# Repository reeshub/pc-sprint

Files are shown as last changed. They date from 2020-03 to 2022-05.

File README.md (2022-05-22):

# PC-SPRINT

## Navigating This Document

This README has become somewhat unwieldy, so here's an index.

- [Introduction to PC-SPRINT](#introduction-to-pc-sprint) - A quick introduction to the device and how it works.
  - [YouTube Video](#youtube-video) - A YouTube video for those who aren't keen on reading
- [Original File Listing](#original-file-listing) - The original design and accompanying files as released by Doug Severson in 1985.
- [Retro Canada KiCAD Files](#retro-canada-kicad-files) - KiCAD and gerber files drawn up by [VCFed Forum](http://www.vcfed.org/forum/forum.php) user "Retro Canada" for PCB fabrication.
- [My Own "Retro Canada" Board](#my-own-retro-canada-board) - I had a PCB fabricated and assembled it using the above files.
  - [My Testing](#my-testing) - Notes from my own tests with this board.
  - [My Benchmarks](#my-benchmarks) - Benchmarking results.
    - [Landmark](#landmark) - Results from the Landmark benchmarking tool. 
	- [TOPBENCH](#topbench) - Results from the TOPBENCH benchmarking tool.
	- [CheckIt](#checkit) - Results from the CheckIt diagnostic / benchmarking tool.
	- [MIPS](#mips) - You guessed it. Results from the MIPS benchmarking tool.
	- [Benchmarking Conclusions](#benchmarking-conclusions) - Conclusions on benchmark results.
- [Everything Else](#everything-else) - Other interesting documentation and bits and bobs.
- [License](#license) - Licensing information for this project and documentation.

## Introduction to PC-SPRINT

The PC-SPRINT is a DIY PC accelerator board design released by Doug Severson in 1985 and given away for free in computer magazines and on BBSes of the time. It is designed to allow overclocking of an [Intel 8088](Datasheets/Intel%208088%20Datasheet.pdf)-based computer such as the IBM 5150 / 5155 / 5160 PCs, PCjr, Tandy 1000, Compaq Portable<sup>*</sup>, and I'm sure a whole lot more.

It is highly recommended that the CPU be upgraded to an [NEC V20](https://en.wikipedia.org/wiki/NEC_V20) or equivalent, as the standard 8088 shipped with these early machines will probably not run at clock speeds over the original 4.77MHz. Also the 8087 co-processor, if fitted, will need to be a higher clocked version.

<sup>*</sup> The PC-SPRINT has now been tested with a Compaq Portable 1 and works great! There are a few things to bear in mind which are referenced in [issue #1](/../../issues/1). Many thanks to @cognitivegears for the excellent feedback.

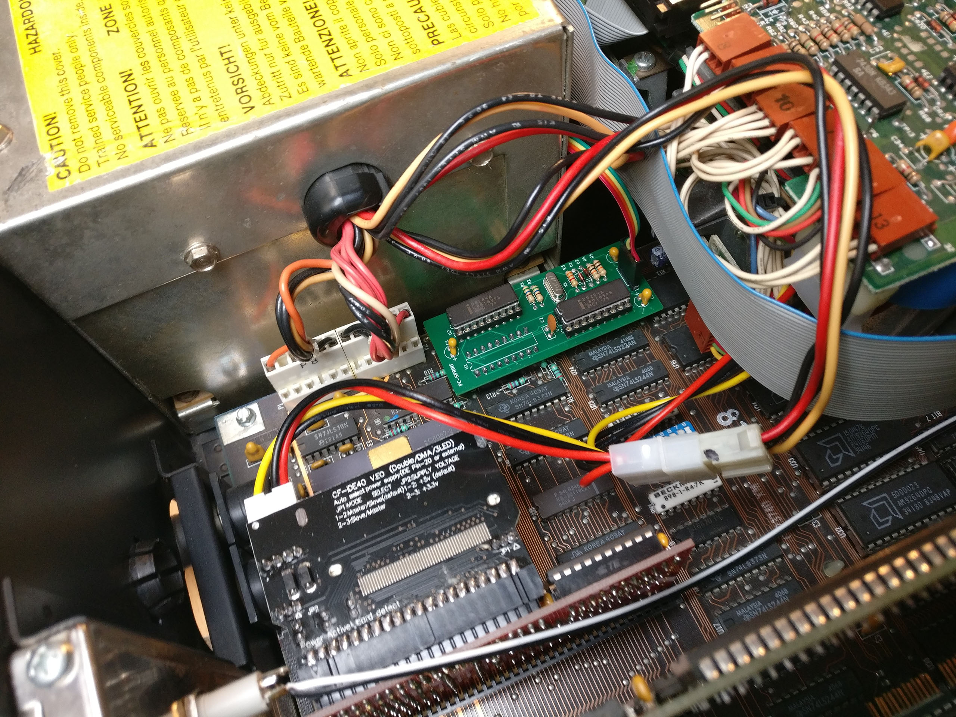
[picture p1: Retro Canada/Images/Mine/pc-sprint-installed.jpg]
My PC-SPRINT Installed In My IBM 5150


In these machines and other contemporary "PC Compatibles" the system clock is usually generated by a 14.318MHz crystal connected to an [Intel 8284A](Datasheets/Intel%208284A-1%20Datasheet.pdf) Clock Generator Driver. The 8284A divides the crystal's signal by 3 giving us our 4.77MHz clock. Unfortunately we can't just replace the crystal on the motherboard as this would play havoc with all sorts of things. The basis of this accelerator is to provide an additional, faster crystal coupled with an additional 8284A to generate a faster clock signal that will be used exclusively by the CPU.

The PC-SPRINT also adds a "Turbo" switch as found on later PCs to enable / disable the higher clock rate and a hardware reset button, which is lacking on the IBM 5150. The included [WARMBOOT.COM](WARMBOOT.COM) utility sets a BIOS flag which skips the RAM test on a warm boot, making the reset very fast even at stock speed.

When the PC-SPRINT is built with the designer's recommended 22.11MHz crystal the CPU will run at a clock speed of 7.37MHz giving an impressive 64% processing speed increase (on paper). Faster speeds may be possible with faster crystals but were not recommended for stability reasons. Note that in order to utilise this accelerator the original 4.77MHz 8088 CPU must be replaced with either a faster version of the same CPU (e.g. 8088-2) or equivalent clone (e.g. [NEC V20](https://en.wikipedia.org/wiki/NEC_V20), which is highly recommended as it brings other benefits).

Much more information is available in the [original documentation](PCSPRINT.DOC) ([PDF](PCSPRINT.DOC.PDF)).

### YouTube Video

I have now also put together a short introductory video. Unfortunately it can't be embedded here, so please click the image below to be taken to YouTube:

PC-SPRINT 8088 Overclocking Tool / Accelerator YouTube Video (https://youtu.be/8oWyogPZ7Bw)

## Original File Listing

Here is a rough index of the files included with the package as originally distributed:

- [1STREAD.ME](1STREAD.ME) - Listing of project files (you're reading a modern adaptation of this)
- [ARTWRK1X.BOT](ARTWRK1X.BOT) - Bottom layer printed circuit artwork 1x size (obsolete printer format) ([PDF](ARTWRK1X.BOT.PDF))
- [ARTWRK1X.TOP](ARTWRK1X.TOP) - Top layer printed circuit artwork 1x size (obsolete printer format) ([PDF](ARTWRK1X.TOP.PDF))
- [ARTWRK2X.BOT](ARTWRK2X.BOT) - Bottom layer printed circuit artwork 2x size (obsolete printer format) ([PDF](ARTWRK2X.BOT.PDF))
- [ARTWRK2X.TOP](ARTWRK2X.TOP) - Top layer printed circuit artwork 2x size (obsolete printer format) ([PDF](ARTWRK2X.TOP.PDF))
- [FEEDTHRU](FEEDTHRU) - Top - bottom "feed through" connection diagram ([PDF](FEEDTHRU.PDF))
- [NOPRTYCK.COM](NOPRTYCHK.COM) - Program to disable parity checks
- [PARTLIST](PARTLIST) - Parts list & placement drawing ([PDF](PARTLIST.PDF))
- [PCSPRINT.BAT](PCSPRINT.BAT) - Batch file to print PC-SPRINT info & drawings 
- **[PCSPRINT.DOC](PCSPRINT.DOC) - Description & construction info ([PDF](PCSPRINT.DOC.PDF))**
- [SCHEMATC](SCHEMATC) - Electronic circuit diagram ([PDF](SCHEMATC.PDF))
- [WARMBOOT.COM](WARMBOOT.COM) - Program to set "warm boot" flag

Note that some files have PDF conversions which were included with the version of the package as received by myself, so I have also linked those above.

The author was keen to include the original unmodified package of files with future revisions, so it is available in [pcsprint_1985.zip](References/pcsprint_1985.zip).

## Retro Canada KiCAD Files

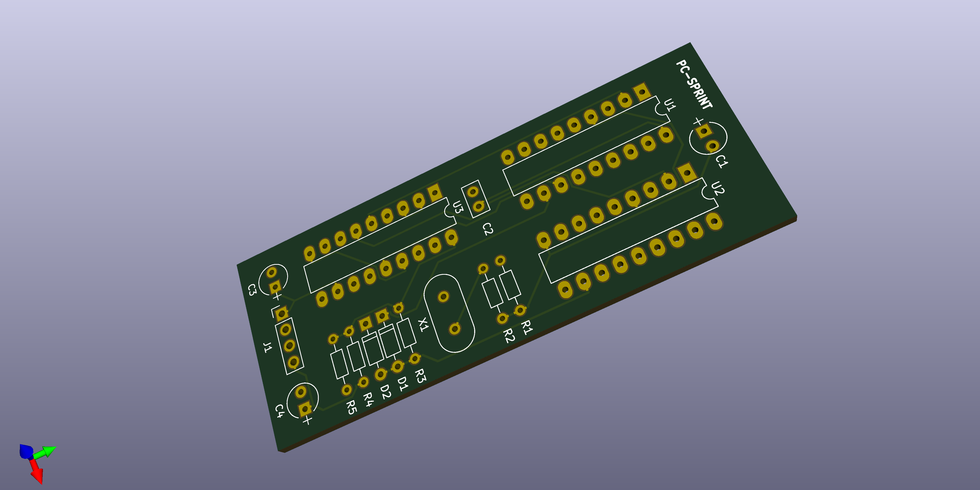
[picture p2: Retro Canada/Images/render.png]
3D Render of Retro Canada's PC-SPRINT


A Vintage Computer Federation forum user by the name of Retro Canada [redrew the original PCB design in KiCAD](http://www.vcfed.org/forum/showthread.php?60803-I-overclocked-my-IBM-5150) and [released the files freely](https://sites.google.com/site/tandycocoloco/dropbox/PC-SPRINT.zip) on November 26th 2017.

I have added a mirror of this KiCAD project [here](Retro%20Canada/PC-SPRINT.zip). The package includes gerber files so KiCAD is not required if you are planning on sending the files directly to a PCB fabricator.

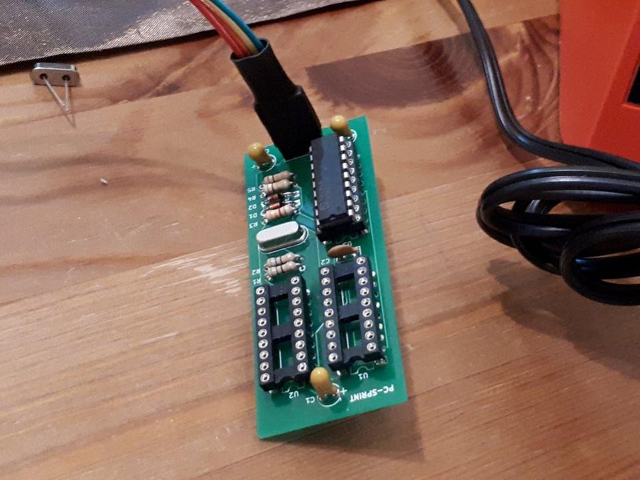
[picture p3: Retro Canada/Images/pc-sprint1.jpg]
Retro Canada's PC-SPRINT


The user built their own based on these files (pictured above - [more of their pictures here](Retro%20Canada/Images)) but could only get it to run reliably up to a 17.43MHz crystal (CPU clock speed 5.81MHz). It is believed that this is related to DMA activity and/or RAM speed, however without the rest of their system specs it's hard to be sure.

### My Own "Retro Canada" Board

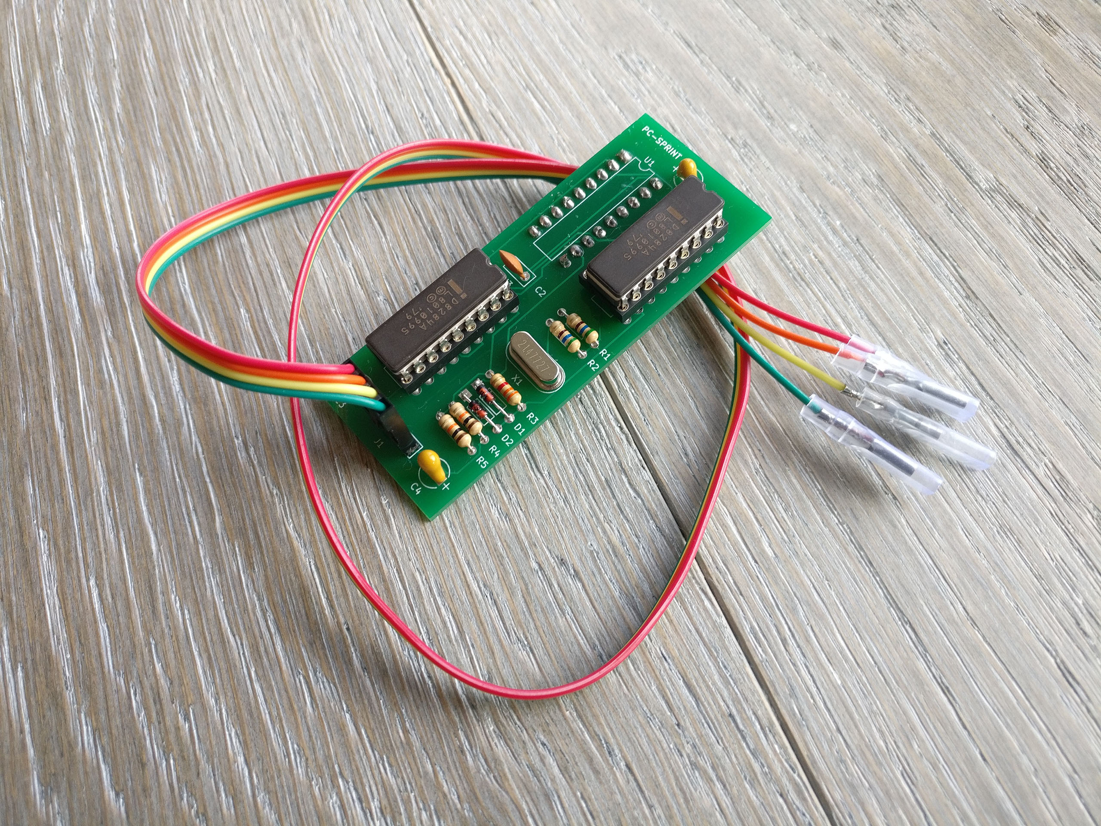
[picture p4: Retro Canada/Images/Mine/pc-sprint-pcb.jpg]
My PC-SPRINT Built Using Retro Canada's Gerber Files


I also successfully built and tested a PC-SPRINT using Retro Canada's files. I used [PCBWay](https://www.pcbway.com/) for my PCB fabrication. Mine has a 21.47727MHz HC-49S crystal giving a CPU clock speed of 7.16MHz - the same as the popular [Tandy 1000 EX and HX](https://en.wikipedia.org/wiki/Tandy_1000#Tandy_1000_EX_and_HX) machines. Thankfully after extensive testing I haven't run into any of the issues experienced by Retro Canada, even at this higher speed.

I have experimented with 22.11MHz and even 24MHz crystals and encountered stability issues at these speeds, so I recommend starting at 21.47MHz.

#### My Testing

Here are the specs of my IBM 5150 as tested:

|Part|Model|Notes|
|---|---|---|
|CPU|[NEC V20](https://en.wikipedia.org/wiki/NEC_V20)|4.77MHz stock / 7.16MHz "turbo" with PC-SPRINT|
|FPU|[Intel 8087-2](https://en.wikipedia.org/wiki/Intel_8087)|8087 co-processor rated up to 8MHz|
|RAM|640KB|(256KB onboard, 384KB on SixPakPlus card)<sup>*</sup>|
|Motherboard|64-256KB [Later Revision](http://www.minuszerodegrees.net/5150/motherboard/5150_motherboard_revisions.htm)|[10/27/82 BIOS](http://minuszerodegrees.net/5150/bios/5150_bios_revisions.htm)|
|HDD|XT-IDE with 512MB CompactFlash card|Running [IDE_XTP.BIN BIOS](https://www.lo-tech.co.uk/wiki/XTIDE_Universal_BIOS)|
|Graphics|IBM CGA<sup>**</sup>||
|Network|3com EtherLink II||
|Floppy|2x Tandon 360KB 5.25"|Stock IBM Floppy ISA interface|
|PSU|Standard 110VAC / 63.5W|
|Operating System|[IBM PC DOS 2000](https://winworldpc.com/product/pc-dos/2000)||

<sup>\* All RAM chips were recently replaced with "New Old Stock" [Samsung KM4164B-15](http://www.minuszerodegrees.net/memory/4164.htm) parts, which have a 150ns access time.</sup>
<sup>\** I have since upgraded to an IBM EGA card (with RAM expansion) and can confirm that the PC-SPRINT works great with this setup. Benchmarks below use the CGA card.</sup>

I have done extensive testing with the above system and had no problems whatsoever. I was expecting issues with DMA activity as others have reported, however have seen none at all. Perhaps this is due to the XT-IDE and its [unusual handling of DMA](https://www.lo-tech.co.uk/xt-cfv3-dma-transfer-mode/). The PC even boots up fine with the turbo mode engaged. Incidentally, cold boot time is 1:02 stock vs. 43 seconds in turbo mode.

The included NOPRTYCHK and WARMBOOT utilities work exactly as advertised with no issues as does the new reset button.

The picture below shows how I installed the turbo and reset buttons in the case. Both are 12mm panel mount push buttons - the turbo button is a latching version:

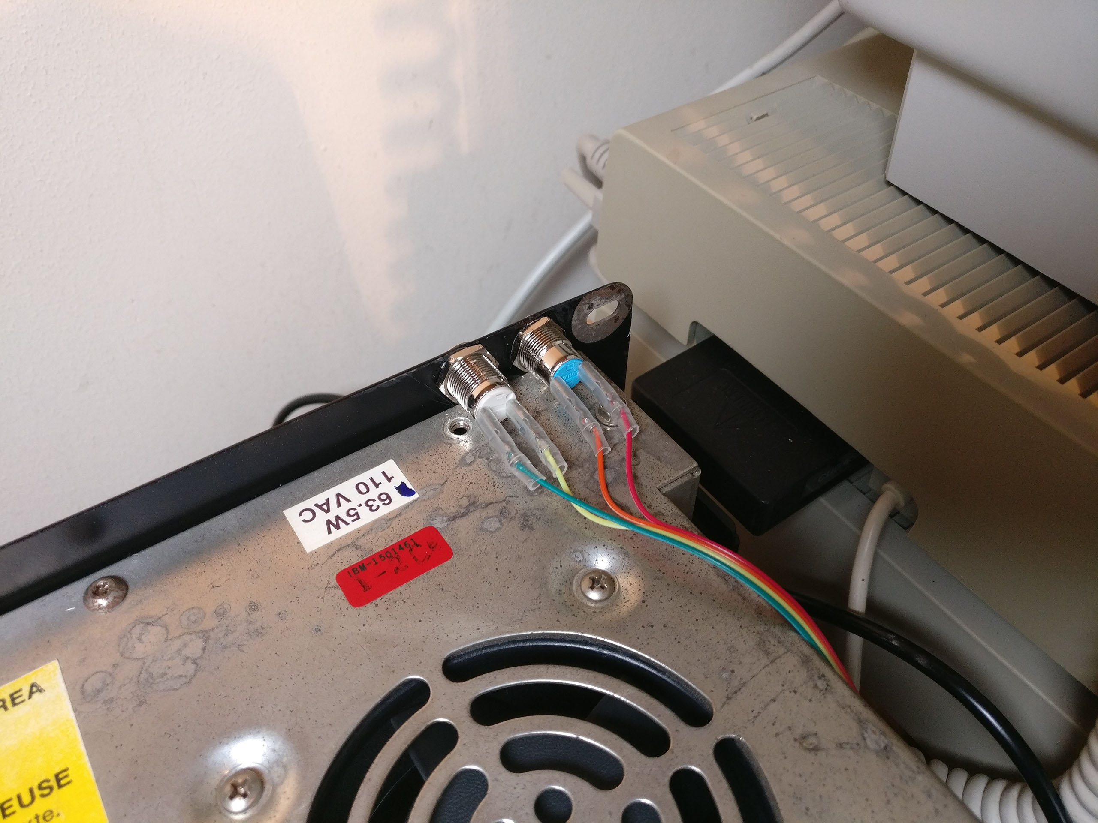
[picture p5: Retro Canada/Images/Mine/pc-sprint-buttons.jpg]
My PC-SPRINT Reset and Turbo Buttons


### My Benchmarks

I ran through a series of benchmarking applications in both turbo and non-turbo mode.

These screenshots (and the videos on [my YouTube channel](https://www.youtube.com/ctrlaltrees)) were captured with a rather elaborate capture setup involving a [CGA2RGB](https://gglabs.us/node/2063), [OSSC](https://videogameperfection.com/products/open-source-scan-converter/) and a [StarTech USB3HDCAP](https://www.startech.com/uk/AV/Converters/Video/usb-3-0-video-capture-device-hdmi-dvi-vga~USB3HDCAP), but that's a tale for another time.

These benchmarks compare the performance of the NEC V20 CPU in stock 4.77MHz and turbo 7.16MHz modes using the PC-SPRINT. Unfortunately I don't have the original Intel 8088 CPU anymore to be able to test, however for some indication of how this system performs compared to a stock 5150 take a look at the [MIPS](#mips) benchmark below.

With the exception of CheckIt, all of these benchmarking tools were downloaded from the [TOPBENCH Other Benchmarks](https://dosbenchmark.wordpress.com/otherbenchmarks/) page.

#### Landmark

Landmark System Speed Test was released in 1984 by Landmark Research Internation Corporation and was one of the first DOS benchmarking tools. Here I'm using version 6.00, the final release from 1993.

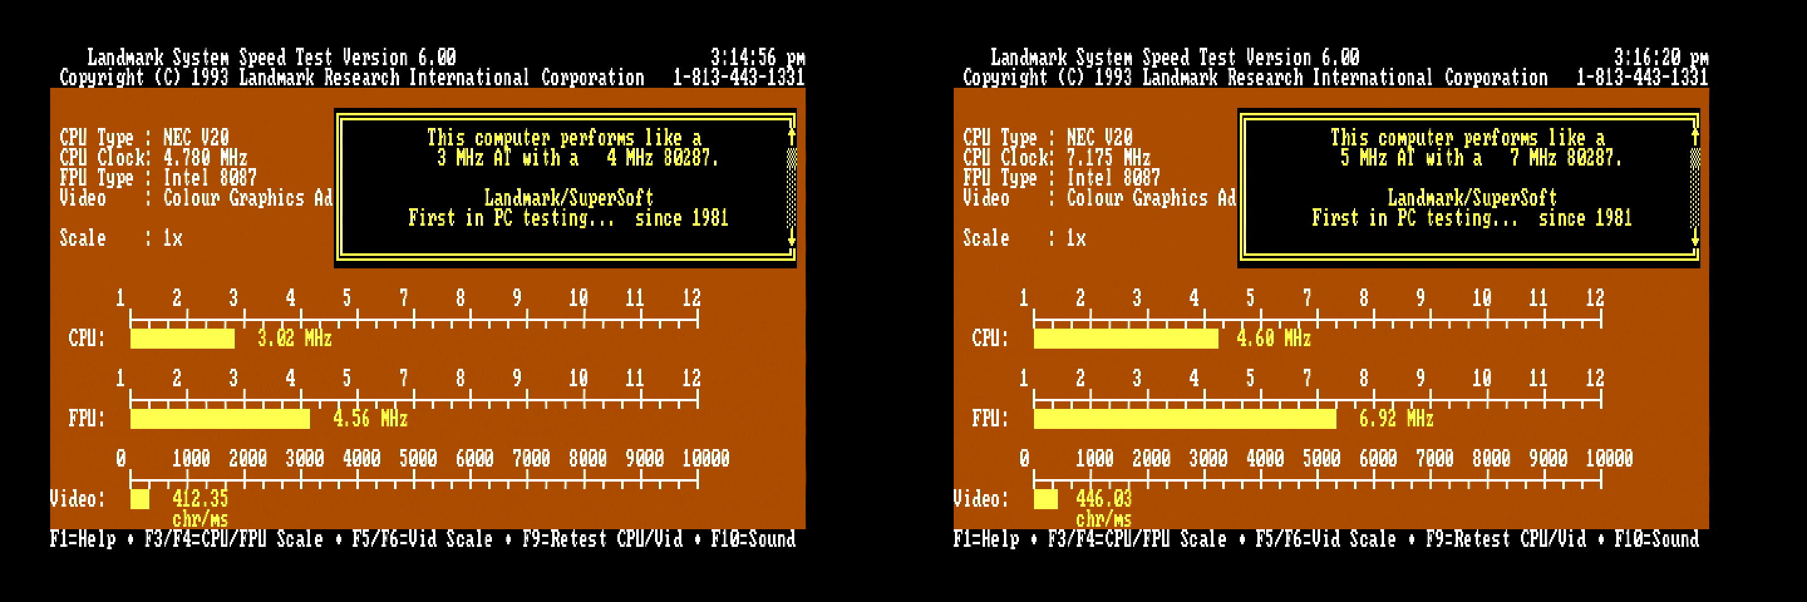
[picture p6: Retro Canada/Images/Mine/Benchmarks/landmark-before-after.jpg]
Landmark Benchmark Before And After Results


|Benchmark|V20 Stock|V20 Turbo|Improvement|
|---|---|---|---|
|CPU<sup>*</sup>|3.02MHz|4.60MHz|52.32%|
|FPU|4.56MHz|6.92MHZ|51.75%|
|Video|412.35 chr/ms|446.03 chr/ms|8.17%|

<sup>\* The way this figure is calculated is interesting (and generally considered wrong) but the percentage increase is all that matters to us. There is more information on the way Landmark arrives at their CPU figure [here](https://dosbenchmark.wordpress.com/research/landmark/).

#### TOPBENCH

[TOPBENCH](https://dosbenchmark.wordpress.com/) is a modern realtime DOS benchmarking tool. An interesting feature is its "database", which allows you to compare your system's performance to that submitted by other users. I'm using version 0.38 with the full database.

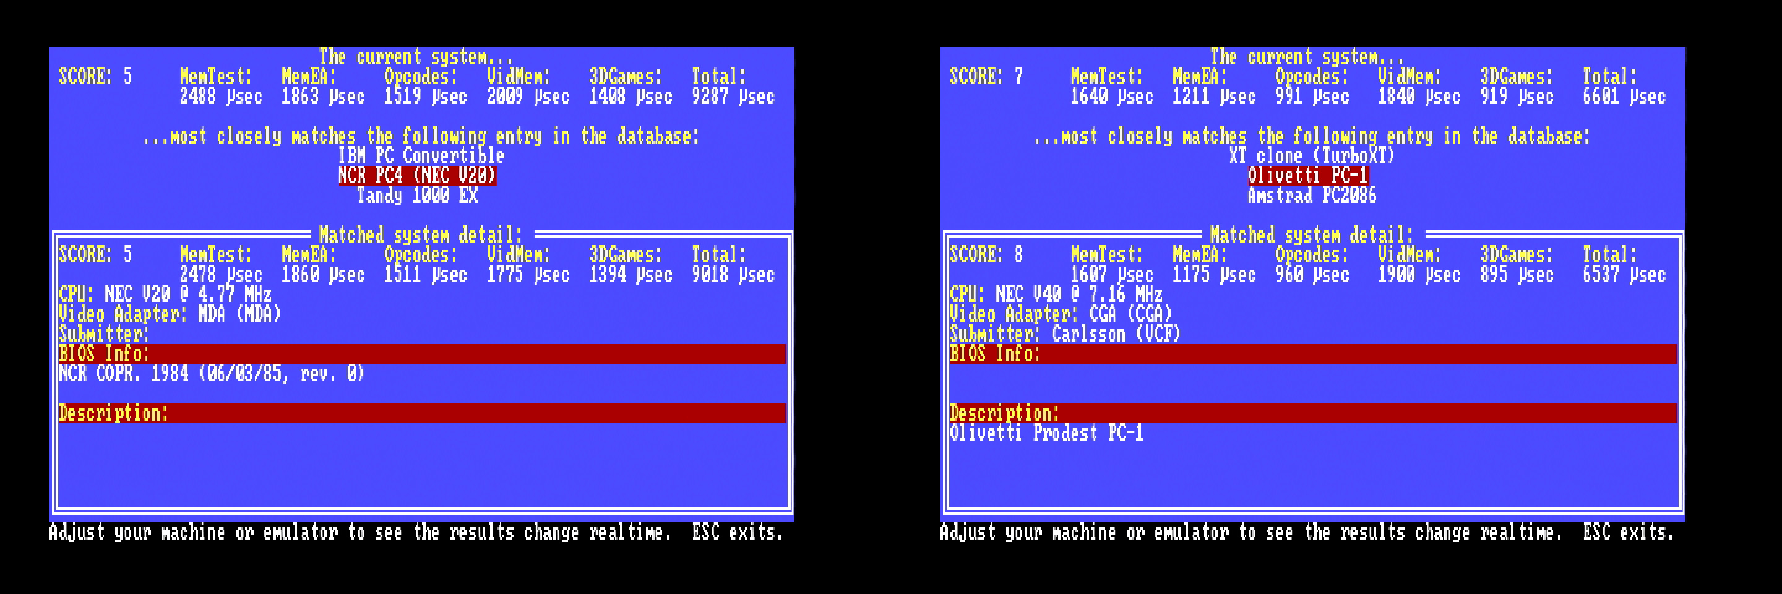
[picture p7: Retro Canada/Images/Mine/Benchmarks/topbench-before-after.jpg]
TOPBENCH Benchmark Before And After Results


Note that TOPBENCH reports the run times of its tests in microseconds, so a lower score is better (faster).

|Benchmark|V20 Stock|V20 Turbo|Improvement|
|---|---|---|---|
|TOPBENCH Score|5|7|2|
|MemTest|2488μ|1640μ|51.71%|
|MemEA|1863μ|1211μ|53.84%|
|Opcodes|1519μ|991μ|53.28%|
|VidMem|2009μ|1840μ|9.18%|
|3DGames|1408μ|919μ|53.21%|
|Total|9287μ|6601μ|40.69%|

According to the database we've gone from an NCR PC4 to an Olivetti PC-1. As I'm not familiar with either of these machines I guess I'll just have to take their word for it. ;)

#### CheckIt

From [WinWorldPC](https://winworldpc.com/product/checkit/30), who said it better than I ever could:

CheckIt, from TouchStone Software Corporation, is a diagnostic tool for generic PC/XT/AT compatible computers. It can perform tests on RAM, hard disks, video cards, floppy disks, motherboard resources, and I/O devices. It has an easy to use menu interface but can also run tests non-interactively.

I'm running version 3, the last release from 1990. In each of these screenshots the "Stock" value (top grey line) is the NEC V20 with turbo mode off.

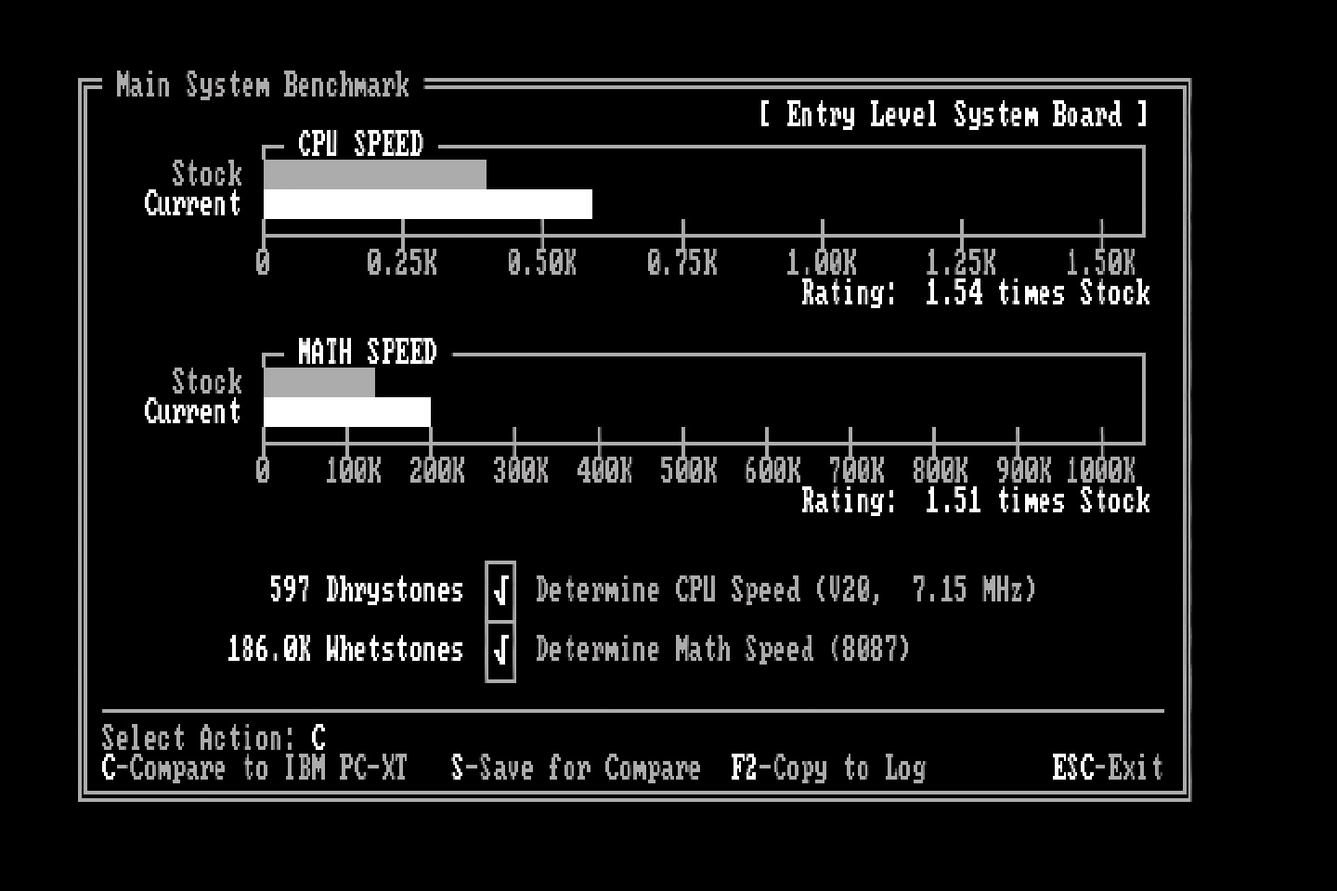
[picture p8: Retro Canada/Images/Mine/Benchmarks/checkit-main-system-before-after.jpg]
CheckIt CPU Benchmark Before And After Results


|Benchmark|V20 Stock|V20 Turbo|Improvement|
|---|---|---|---|
|CPU [Dhrystones](https://en.wikipedia.org/wiki/Dhrystone)|387|597|54.26%|
|FPU [Whetstones](https://en.wikipedia.org/wiki/Whetstone_(benchmark))|123.1K|186K|51.1%|

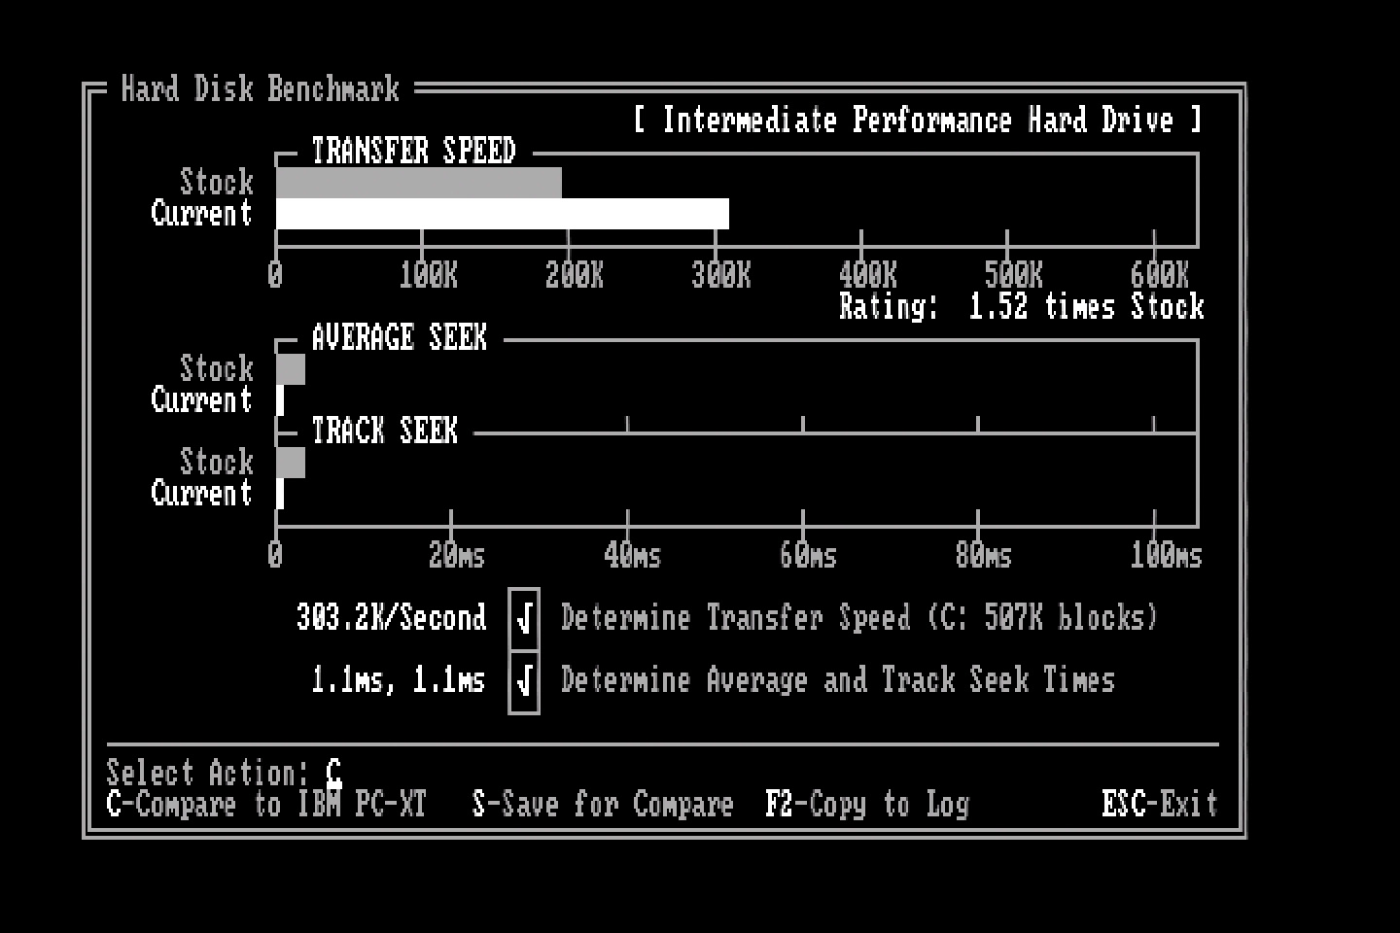
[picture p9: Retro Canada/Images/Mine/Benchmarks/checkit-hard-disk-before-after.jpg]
CheckIt Hard Disk Benchmark Before And After Results


|Benchmark|V20 Stock|V20 Turbo|Improvement|
|---|---|---|---|
|Transfer Speed|198.9K/sec|303.2K/sec|52.44%|
|Average Seek Time<sup>*</sup>|1.7ms|1.1ms|54.55%|
|Track Seek Time<sup>*</sup>|1.7ms|1.1ms|54.55%|

<sup>\* Note that when it comes to seek times, lower numbers are better.</sup>

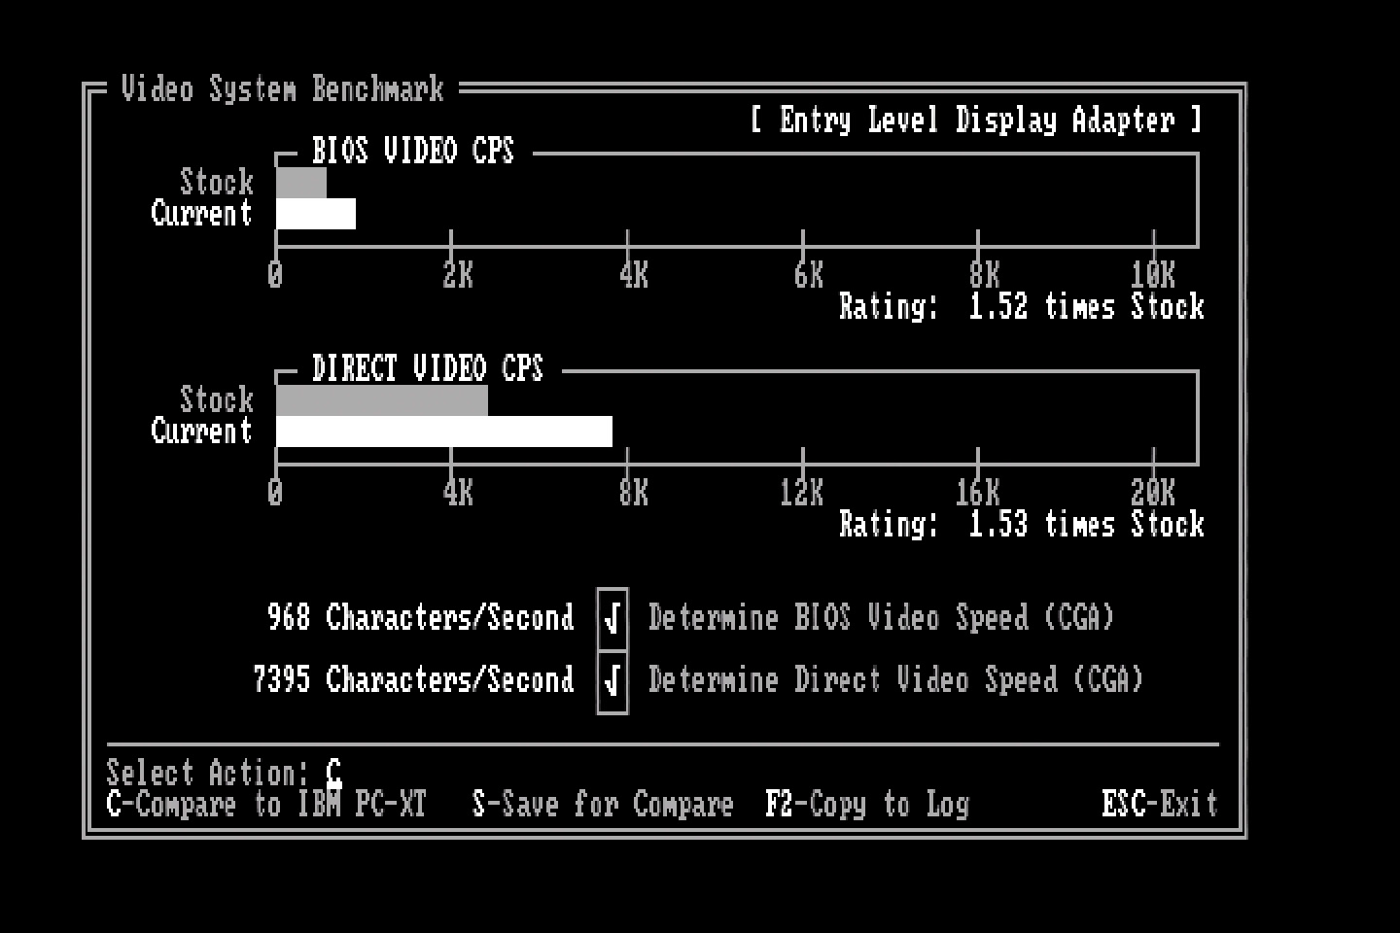
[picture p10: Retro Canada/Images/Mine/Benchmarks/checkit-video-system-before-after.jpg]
CheckIt Video System Benchmark Before And After Results


|Benchmark|V20 Stock|V20 Turbo|Improvement|
|---|---|---|---|
|BIOS Video Speed|637chr/sec|968chr/sec|51.96%|
|Direct Video Speed|4837chr/sec|7395chr/sec|52.88%|

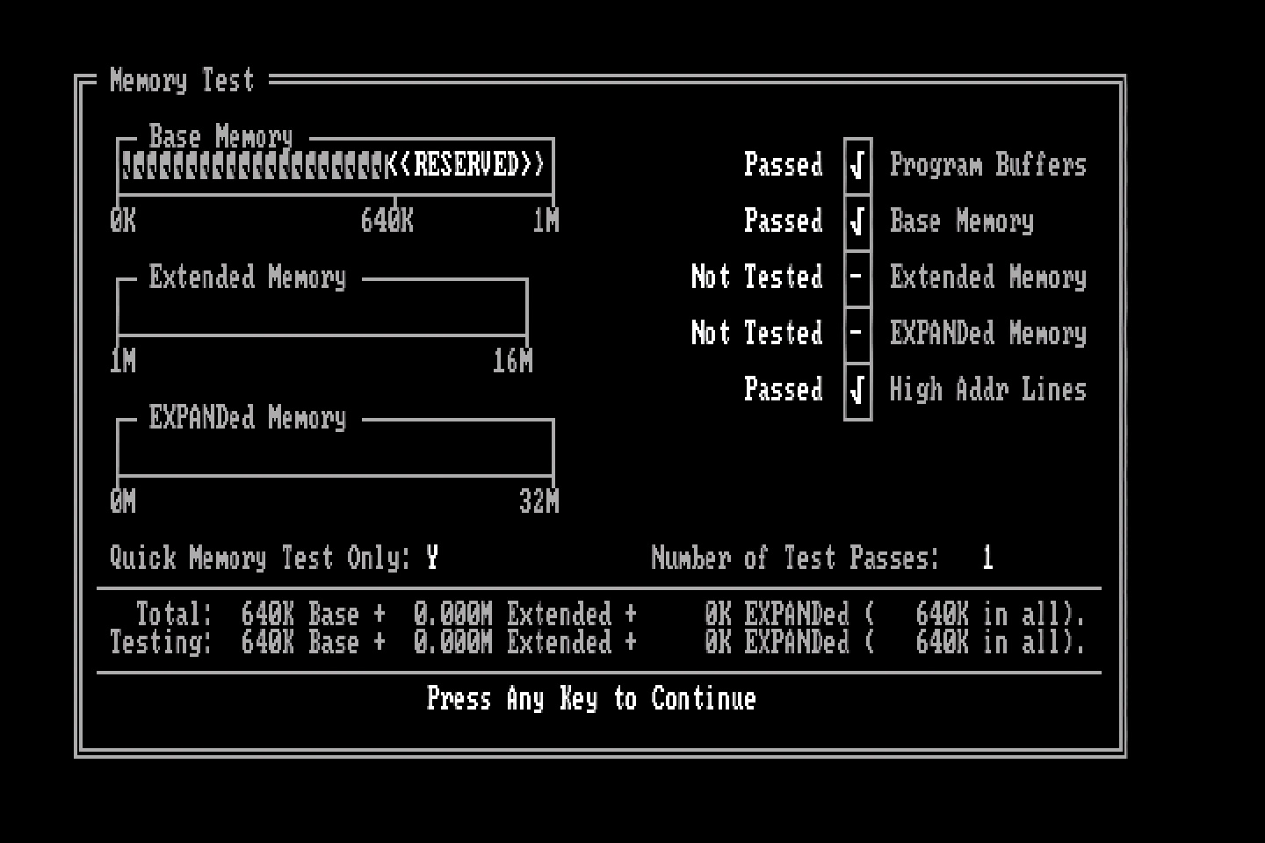
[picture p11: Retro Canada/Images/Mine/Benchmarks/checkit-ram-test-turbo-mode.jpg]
CheckIt RAM Test Results - Turbo Mode


I also ran various RAM tests with turbo enabled to see if it would pick up any errors, but all tests passed with no problems.

#### MIPS

Chips & Technologies MIPS was written by Jim Bracking and released in 1986. It's a very comprehensive test covering various number-crunching operations, and even shows your score compared to typical examples of machines of that era - an IBM PC, PC/AT and a Compaq 386.

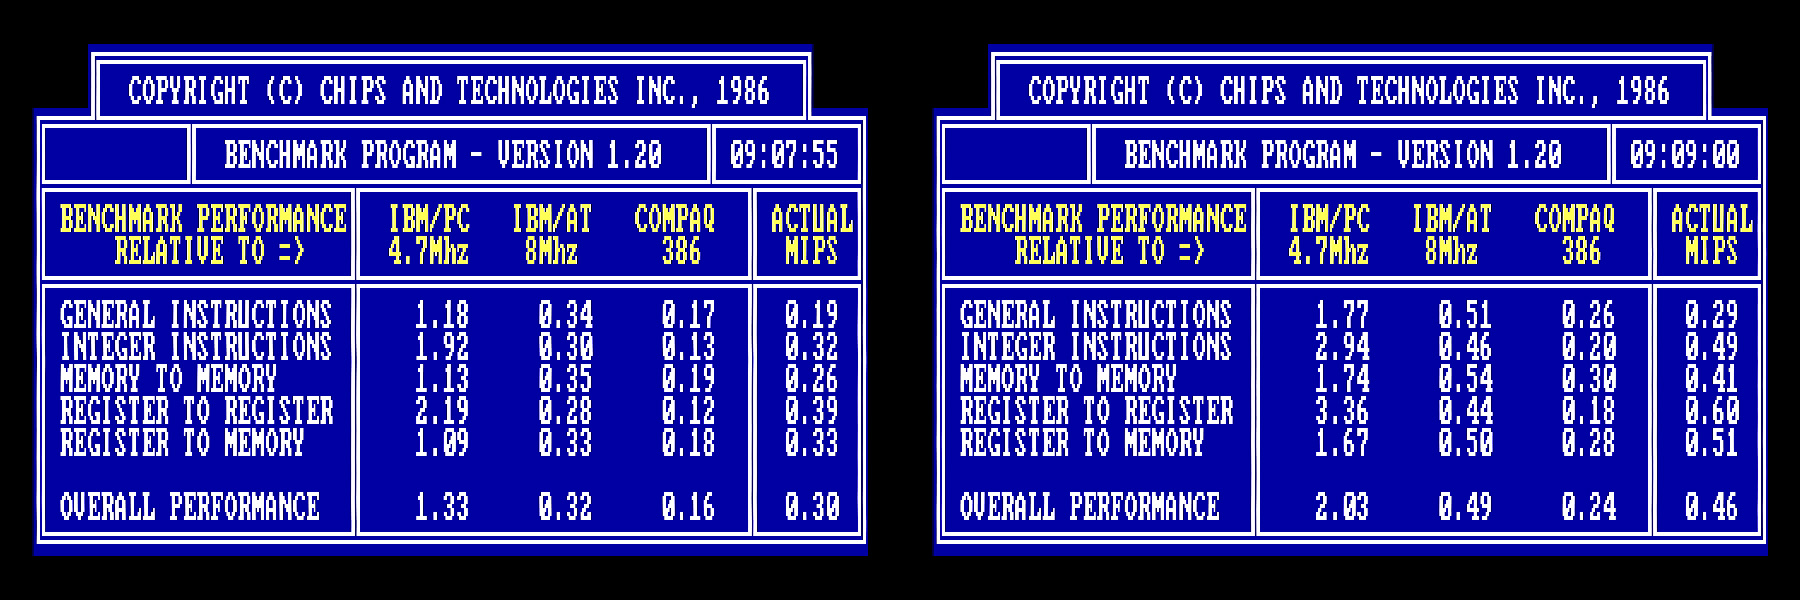
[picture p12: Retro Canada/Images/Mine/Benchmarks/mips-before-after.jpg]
MIPS Benchmark Before And After Results


|Benchmark|V20 Stock|V20 Turbo|Improvement|
|---|---|---|---|
|General Instructions|0.19|0.29|52.63%|
|Integer Instructions|0.32|0.49|53.12%|
|Memory To Memory|0.26|0.41|57.69%|
|Register To Register|0.39|0.60|53.85%|
|Register To Memory|0.33|0.51|54.55%|
|Overall Performance|0.30|0.46|53.33%|

MIPS also shows that our overclocked NEC V20 is over twice as fast as a stock IBM 5150 running an Intel 8088 CPU.

### Benchmarking Conclusions

As we can see, the speedup on all fronts is in the region of 50-55%, which is a massive improvement for around £6 worth of components. According to [MIPS](#mips), with the addition of the V20 and the overclock this machine is now twice as fast as a standard IBM PC. I haven't encountered any stability issues but my testing is ongoing and of course, if I come across them I will document them here.

Finally, of course benchmarks are entirely artificial and don't necessarily reflect real world results. In my testing I have found that, without exception, every single game on this machine (and I have a fair few) is more playable with massively reduced slowdowns and stuttering. That's a hard thing to quantify, however, so with that in mind I am working on a series of comparison videos which should hopefully be available [on my YouTube channel](https://www.youtube.com/ctrlaltrees) soon.

There is now [a general overview of my overclocked IBM 5150 on YouTube](https://youtu.be/Y7NNCWvt1nY) for anyone interested.

### Everything Else

Here I'll collect any other odd bits of info I can find on the PC-SPRINT.

[pcspnt.txt](Everything%20Else/Documents/pcspnt.txt) - PC-SPRINT 1000 by Charles Robertson (1988-08-13). Information relating to the installation of the PC-SPRINT in the Tandy 1000A. \[[source](http://www.oldskool.org/guides/tvdog/documents.html)\]

## License

The PC-SPRINT was originally released with the following licensing conditions:

> License to duplicate, distribute and use PC-SPRINT is hereby granted to individuals, for personal use, and non-profit organizations with the following conditions:
> 
> 1. All files in this package must be distributed intact and unmodified.
> 2. No fees may be charged (other than reasonable duplication costs) for this package or any printed circuit board made by its use.
> 3. All commercial rights to this package remain the property of the author.
> 4. Hobby or user oriented magazines may reprint all or portions of this package, as long as credit is given to the author.
> 5. For-profit organizations may obtain a license by contacting the author.
> 6. The author will not be held liable for any damages or injuries, direct or subsequent, that may result from its distribution, construction, installation or use.

Attempts have been made to track down the author but to no avail, so this project is shared here in good faith that the sentiments of the original designer will be honoured.

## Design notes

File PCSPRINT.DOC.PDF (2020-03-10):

1. DESCRIPTION

PC-SPRINT is a low cost ($25 - $50) speed up for the IBM PC/XT that you can build yourself. It can achieve processor performance increases of up to 2 times normal, does not use an expansion slot, doesn't make any permanent changes to the computer and maintains software compatibility without restrictions. As an additional bonus, it adds a true hardware reset - no more "keyboard lockup".

PC-SPRINT is also an experiment to determine if hardware designs can be placed in the public domain, as a type of "freeware", and be distributed by electronic means only. This package contains all the information needed to build PC-SPRINT, including instructions, schematics, part placement diagrams, and precision artwork from which a printed circuit board can be made. Although this sounds rather formidable, PC-SPRINT should be within the capabilities of the average electronic hobbyist. I would appreciate your comments on this project, and the experiment in general. You are welcome to send me a note at the following address.

Doug Severson
7431 W. Southview Dr.
Franklin, Wi. 53132

2. CAVEATS

As an old "hardware hacker", I consider this project simple and straight forward - but that's easy for me to say. If you feel nauseous at the mere thought of removing your PC's cover, pass this up or get help. Maybe your user's group could arrange to have some made at reasonable cost.

The claims made here are real - this package was done on a PC running an 8 megahertz (mhz) V20 processor at 7.37 mhz. The actual performance increase provided by PC-SPRINT depends on what your particular computer can handle, and on choice of processor. In my case, the faster clock provides a factor of 1.55X (7.37/4.77); the V20 is variously rated at 1.1 to 1.4X over an 8088 at the same clock, giving an overall factor somewhere between 1.7 and 2.1X.

Unfortunately, a 7.37 mhz clock, with no "wait states", pushes the PC's design to its limit. Your particular setup may not be capable of full speed, but with a simple component change to PC-SPRINT (explained later), you can find your machines maximum. If your PC has a 5 mhz 8087 (number cruncher chip), it must also be replaced along with your original 8088.

If you do decide to give this a try, check one very important detail before committing any time or money - PC-SPRINT depends on replacing the PC's 8284A clock IC with a circuit board - on most PC's and XT's I've seen, this chip is socketed and easily removeable. However, this is not true for all machines. Using the directions given in the installation section, open up your PC, locate its 8284A, and make sure it is in a socket. If not, you must unsolder it from the motherboard and put a socket in its place. This isn't too difficult, but may not worth the effort.

3. CONSTRUCTION

The parts list shows all components needed to build PC-SPRINT; Radio Shack catalog numbers are given for some parts as a reference. Most items should be available by mail order - check the ads in BYTE or RADIO ELECTRONICS. As resistor/capacitor values are not critical, substitutions can be made freely - but try to keep within +/- 10%. Make sure that the processor you order (8088 or V20) is rated at 8 mhz. Its also a good idea to get extra crystals (18.342 mhz or 20 mhz) just in case your PC won't run at full speed. The external switches can be mounted in any convenient manner, but the plastic box specified is handy and cheap. If you can't locate the terminal strip for the cable, it can be directly soldered in the board, but this will make routing the cable more difficult. The square pads on the top of the 2x artwork mark pin 1 of IC's, + side of polarized capacitors, and cathode side of diodes.

The key to building PC-SPRINT is making a printed circuit board from the provided artwork. This mainly entails duplicating (at 1X size) the circuit pattern on a blank copper board, then "etching" away the unused copper not covered by the pattern. Several manual or photographic techniques are possible, using materials made for the purpose. Check with local electronic parts distributors for products or complete kits made by Radio Shack, DATAK, Kepro or G-C Electronics.

I have included 1X and 2X artwork for both sides of the circuit board. Because of printer resolution, the 1X version is really only useful as a placement/routing guide if you manually copy the pattern; use the 2X for details. You do not have to make the board double-sided
- although that makes a neater job of it - just do the bottom and duplicate the top connections with 30 gauge wire. The 2X artwork is very accurate and "camera ready". For both 1X and 2X versions, the "top" or component side, is shown as you would actually view the board from the top. The bottom (solder side) is shown as you would see it if you could look "through" the board from the top; thus it is a "mirror" image and must be flipped over to see how it would be if you saw it from the bottom. This may be confusing, but is standard practice, and really presents no problem for photographic techniques as the negative can be turned over for actual transfer to the board.

Here is a list of some of the ways the board can be made. If you use the 2X artwork directly, check for horizontal breaks on the printout; I've noticed that some printers "drag" a print pin occasionally when doing graphics - the effect should be obvious if it happens.

1) The easiest method is to draw the pattern directly on the bare board, using a special etch resist pen ( available at Radio Shack). This will work, but will likely give poor results.
2) Standard pressure sensitive patterns can be purchased (also at RS) and used to duplicate the layout in a "cut and paste" manner on the copper blank.
3) Using pressure sensitive patterns, copy the artwork on clear plastic sheets, then contact print a negative using printed circuit reversing film. The negative can then be used to contact print the layout on special photo-sensitive copper boards.
4) The best technique is to have the supplied 2X artwork photographically reduced to an actual size negative, then contact print on photo-sensitive boards. A good photo shop can make the negative.

5) A variation of the last technique is to reduce the 2X artwork on an ordinary reducing XEROX machine. A double reduction of 71% will be close enough (0.71 x 0.71 = 0.5041) if the machine can't do half-size. The last reduction can be on "transparency" film, and then used to contact print a negative. Ordinary copier paper can be used, but requires some furthur steps; you can make a "decal" using "lift-it" film (available from electronic suppliers) or spray several coats of clear acrylic on both sides of the paper to make it translucent (this does work - but exposure time more than doubles). In either case, check the final copy for flaws and "touch-up" where necessary with a black fine tip marker.

After the board is etched, cleaned and trimmed to size, check it for shorts and breaks. Drill all holes with a #64 wire gauge drill bit (use a small hand drill or "pin vise"). Slightly enlarge the holes for the cable terminal strip.

Next, solder in the jumpers if you're using a single sided board, or, if double sided, solder pieces of bare wire on both top and bottom to make the feed through connections (see "feedthru sketch"). Trim off excess wire.

Using the "partlist" drawing, place the diodes, resistors and capacitors in the proper holes, forming the leads as you go, and solder in place. Then place a small piece of cellophane tape on the top of the board where the crystal will go to prevent the crystal's case from shorting. Install the crystal vertically and solder in place. Trim off excess wire.

Then install the two 18-pin "solder tail" IC sockets at U2 and U3, and the 18-pin wire wrap socket at U1. Solder all socket connections. Try not to get excess solder on the wire wrap pins, and make sure they are properly connected. Finally, insert the terminal strip and solder in place. Clean off solder flux with rubbing alcohol and a cotton swab. Install the new 8284A in the socket at U3 to complete construction of the board.

To make the switch box, remove the aluminum cover and drill two holes (usually 1/4") for the switches; notch the plastic box for the cable, and install the switches. Next cut the cable to length (3 to 4 feet), nick the insulation on both ends, and split the individual wires apart for a length of 1 to 2 inches. Strip off 1/4" of insulation from each wire end and solder either end of the cable to the switches (use the schematic diagram for the proper connections). It doesn't matter which wires are initially connected to which switch, but write it down since you must know when you insert the cable on the PC-SPRINT board. Make sure you have used the "normally-open" contacts on the push button switch - otherwise, the computer will be held "reset". Replace the switch box cover, placing the cable in the notch so that it doesn't get damaged.

4. INSTALLATION

If you've gotten this far, the rest is easy. The general idea here is to remove and replace the 8088, remove the original 8284A and put it on PC-SPRINT, route the switch cable and install PC-SPRINT in place of the 8284A. As you carry out the following directions, try not to directly touch any chip legs, as static electricity could damage them. Discharge yourself by occasionally touching some large piece of metal, like the computers case.

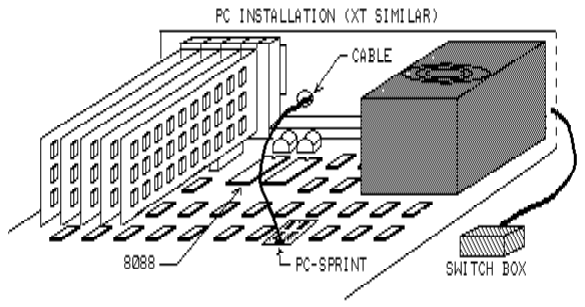
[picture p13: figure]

First, and most important, unplug the computers power cord from the outlet to prevent any possibliity of shock. While you're at it, disconnect all external cables (crt, keyboard, printers, modem, etc.) to protect them from you and you from their power systems.

Using the manufacturers directions, remove the computers case to gain access to the motherboard.

Locate the 8088 processor (40 pin chip), note the direction of the notched end, and very carefully remove it. This may be done by alternately prying up on the ends of the chip a little at a time until it eases out (use a small screw driver or bent piece of metal). Another method is to fashion a 3/8 inch wide, 12 inch long strip of thin, flexible plastic, slide it beneath the chip from either open end, fold upward, and pull on both ends with a rocking motion until the chip pops out (be careful as the chip may fly out with considerable force - keep your face well to the side). Put the old processor into whatever protective packing the new one came in and save it. Insert the new processor into the vacant socket, making sure that the notched end is in the same direction as the original. You may have to bend the chip legs to fit by pushing the chip sideways against a flat surface so that all pins on a side deflect together. Try not to exert excessive downward force on the motherboard as you push the new chip into the socket.

Find the 8284A (18 pin chip - note notch direction) and remove it in a similar manner. On PC's, it's located close to the internal disk drives, around the configuration switch. For XT's, it's towards the back of the case next to the expansion slots. In either case look for the metal crystal can - the 8284A will be very close by. Insert the removed 8284A into the socket at position U2 on the PC-SPRINT board, as shown by the parts diagram.

At this time, route the flat cable from the switches into the computer. Use any convenient path, but make sure that more than enough cable is inside the computer to reach the original 8284A socket (and then some). If you choose to run the cable over the back edge of the chassis, rather than using a back plate hole, protect both sides with electrical tape or use paper binder clips, on both sides, to force the cover to "ride" over the cable. Now open the terminal strip (on the bottom edge of the PC-SPRINT board) by pulling up on its plastic body, insert the pre-stripped ends of the cable into the holes (wire 1 to pin 1, etc), and close by pushing down on the body. Make sure the cable is seated firmly.

Carefully align the underside pins from the PC-SPRINT board with the 8284A socket on the motherboard, checking that the chip notches are in the original direction, and push down firmly until you feel it "grab" in the socket. Check that all pins are seated in the socket (a small mirror might be handy) and that the PC- SPRINT board is level with the motherboard. The cable should be routed upward and gradually fold back over the PC-SPRINT board towards the back of the computer.

You're now done with the installation. Replace the cover, re-attach all cables, place the switch box in a convenient location, plug in the power cord, set the speed switch to normal, hold your breath and power up.

If everything worked ok, the computer should "boot" normally. At DOS prompt, push the reset button - the machine should boot the same as "power-up". Now run some of your programs (use backup copies - just in case) to verify that everything else works. Flip the speed switch to high and re-execute the same programs. They should run noticably faster. Since PC-SPRINT speeds up only the processor, programs that do a lot of I/O work (disk, screen, etc.) won't show much improvement. Processor intensive operations, like spreadsheet recalcs, graphics, in-memory database searches,etc., should be much more responsive.

What if the computer doesn't work now ?.

First, recheck the installation looking for obvious problems such as:
1) cables or power cord not reattached
2) improper PC-SPRINT board installation (misalligned, not fully in socket, wrong socket, etc)
3) processor misaligned or pins bent under the chip (very common)
4) switch cable damage
5) loose switch cable connections
6) reset switch wired to normally closed contacts instead of normally open

If nothing is found at this stage, remove and recheck the PC-SPRINT board for the following:
1) wrong parts or parts not in the correct holes
2) chips, tantalum capacitors or diodes installed backwards
3) crystal can shorting foil traces
4) bad solder joints
5) open or shorted foil traces
6) missing feedthrough wires (double sided) or jumpers (single sided)

Hopefully, you've now found something, fixed it, and are
happily running at high speed. If not, the problem may be more subtle, but still not too difficult to find. You could have a bad processor or other component, but most likely, something just can't handle the speed increase. Except for the processor, the basic design of the PC should be capable of operating at 7.37 mhz, but some adapter and ram expansion boards may not - particularly if somebody cut corners and used 200 ns rams instead of 150 ns types. The thing to do now is to back off the speed a bit. Remove the 22.11 mhz crystal from the PC-SPRINT board and replace it with a 20 mhz or even an 18.43 mhz version - still a substantial speed up.

5. OPERATION

I have included two programs with this package. The first -NOPRTYCK.COM - is a public domain program which stops all memory parity checks (my regards to the unknown author). Some expansion boards will work ok at high speed - except that their parity check circuits are too slow. If you can't boot up at high speed without the infamous "PARITY CHECK x" message, restart at normal speed and execute this program (once between resets) BEFORE switching to high.

The other, WARMBOOT.COM, is a simple program to set the flag which causes the bios to skip memory tests on reset. If you include it in your AUTOEXEC.BAT file, each time you restart with PC-SPRINT's reset button, the computer will come up very quickly (the same as a ctrl-alt-del).

Operation of PC-SPRINT's switches is obvious. The toggle switch determines the speed (high or normal - which way depends on how you wired it) and the reset push button causes a hardware restart without powering down. In use, the speed switch can be changed anytime - even while a program is running - without problem, but try to do it at DOS prompt level. Keep the switch box out of the way so that you don't inadvertantly hit the reset button. When you really want to restart, tap the button firmly but quickly, otherwise the warmboot flag will be lost.

6. THEORY

The basic idea behind PC-SPRINT is simple - run the processor at a higher clock rate and processing speed goes up proportionately. On the IBM AT this can be done merely by replacing the processors' crystal -for the PC & XT things aren't quite so easy for the following reasons:
1) The 8088 processor supplied is specified to run at only 5 mhz.
2) Operation of the timer circuits (interrupt, sound, etc.) ultimately depends on the original frequency which must then remain constant to maintain software compatibility.
3) A few common expansion boards (such as the color graphics adapter) require the original clock to operate correctly.
4) Some programs use "software timing loops", and are therefore processor speed dependent.

PC-SPRINT attempts to solve these problems by running two crystals simultaneously (the original and a higher frequency). This allows changing only the processors clock, while keeping all other frequencies constant. Obviously, the processor must be replaced with a higher speed version.

To gain easy access to the needed connections, PC-SPRINT replaces the 8284A clock generator on the PC's motherboard, but reconnects some of the 8284A's signals through itself, including the oscillator signal, thus keeping that constant.

By adding another 8284A and crystal, a new frequency source is generated which can then be used to drive the unused external frequency input of the original 8284A. The original 8284A will then choose which source to operate from based on the logic level at its F/-C input (high = external, low = crystal) and generate the processors clock accordingly.

The 8284A contains additional circuits to generate processor reset and to select and synchronize the processors "ready" line (used to cause the processor to wait for slow devices). By cross wiring the oscillator outputs of each 8284A to the others external frequency input and using the ready select circuits of the new 8284A, the PERIPHERAL CLOCK output (which feeds the timer circuits on the motherboard) is kept constant at its normal frequency as its source is selected by the same logic signal used for switching the processors clock.

As mentioned previously, the 8284A also generates the processors reset. By "diode or-ing" the motherboard reset line with the debounced output of a momentary switch, a true (as opposed to the software generated "ctrl-alt-del") reset is provided. This "diode or" violates normal logic thresholds, but works in this case because the reset input of the 8284A is a "Schmitt trigger" type with higher than normal levels (when the hysteresis is added).

The unused reset circuit of the added 8284A is combined with the output of a toggle switch to generate the logic level which switches the processors clock, giving manual control of speed. Both the reset switch and the speed switch use a pull up resistor to supply logic "high", and a capacitor to filter switch "bounce". These slow transitions are "squared off" by the Schmitt trigger inputs.

7. COMMENTS

I hope you find PC-SPRINT of some value. I've tried to give as much information as I can without making it my life's career. If interest in this experiment is sufficient, I may add some enhancements to PC-SPRINT in the future, as well as releasing other projects.

GOOD LUCK !

8. LICENSE

License to duplicate, distribute and use PC-SPRINT is hereby granted to individuals, for personal use, and non-profit organizations with the following conditions:

1) All files in this package must be distributed intact and unmodified.
2) No fees may be charged (other than reasonable duplication costs) for this package or any printed circuit board made by its use.
3) All commercial rights to this package remain the property of the author.
4) Hobby or user oriented magazines may reprint all or portions of this package, as long as credit is given to the author.
5) For-profit organizations may obtain a license by contacting the author.
6) The author will not be held liable for any damages or injuries, direct or subsequent, that may result from its distribution, construction, installation or use.

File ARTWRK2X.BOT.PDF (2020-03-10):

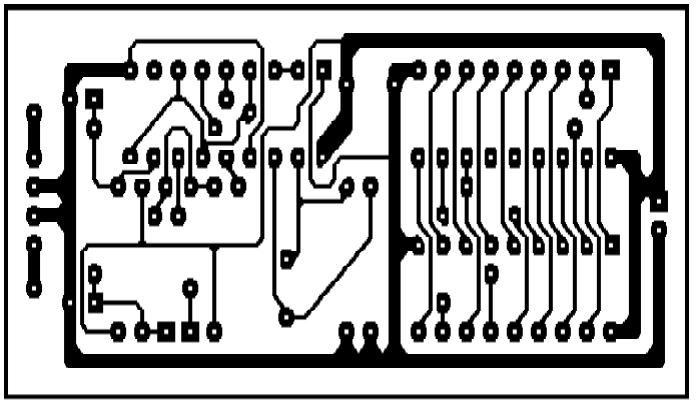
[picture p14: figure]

DOSPrinter 3.1 DEMO (http://www.geocities.com/dosprint)

PC-SPRINT ARTWORK
BOTTOM LAYER (as viewed from above) 2X ACTUAL SIZE
approximate size 1.15 by 2.65 inches
(C) Douglas A. Severson 11/85

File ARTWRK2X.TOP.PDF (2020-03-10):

PC-SPRINT ARTWORK
TOP LAYER
2X ACTUAL SIZE
approximate size 1.15 by 2.65 inches
(C) Douglas A. Severson 11/85

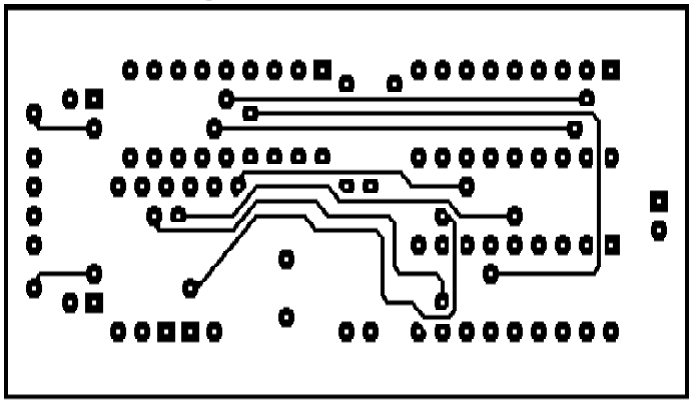
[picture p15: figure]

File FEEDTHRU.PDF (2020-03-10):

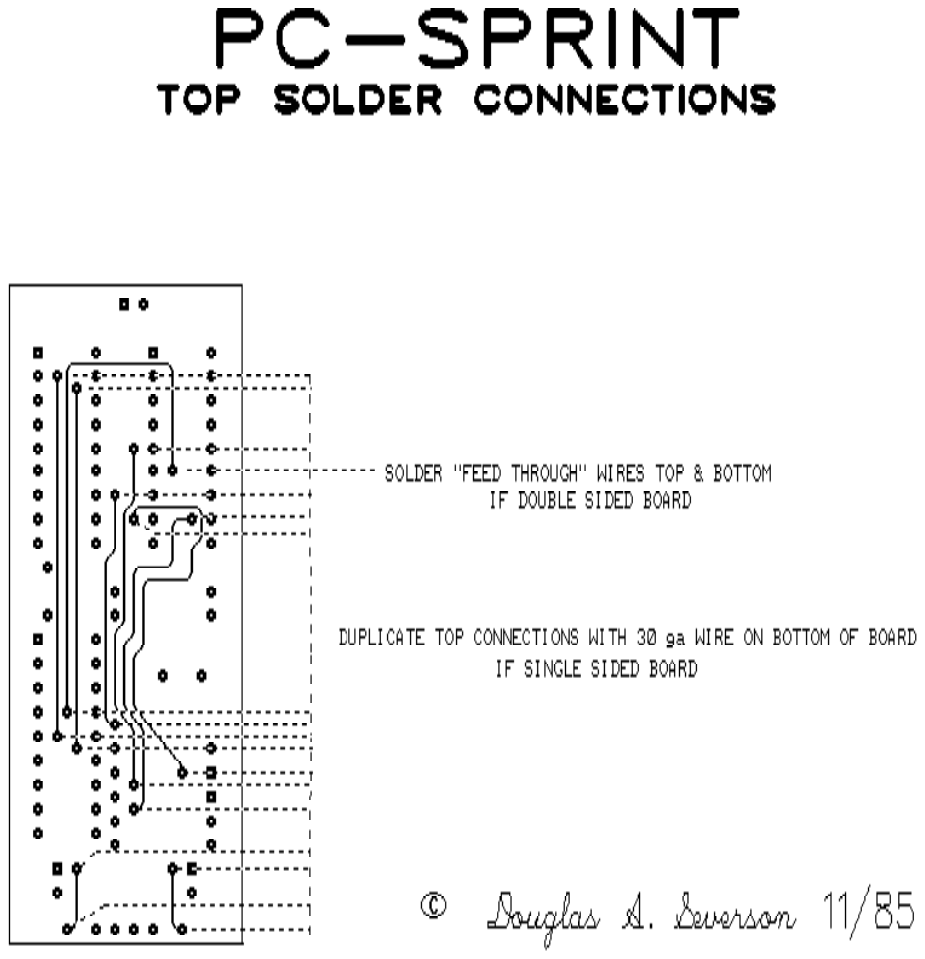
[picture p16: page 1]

0

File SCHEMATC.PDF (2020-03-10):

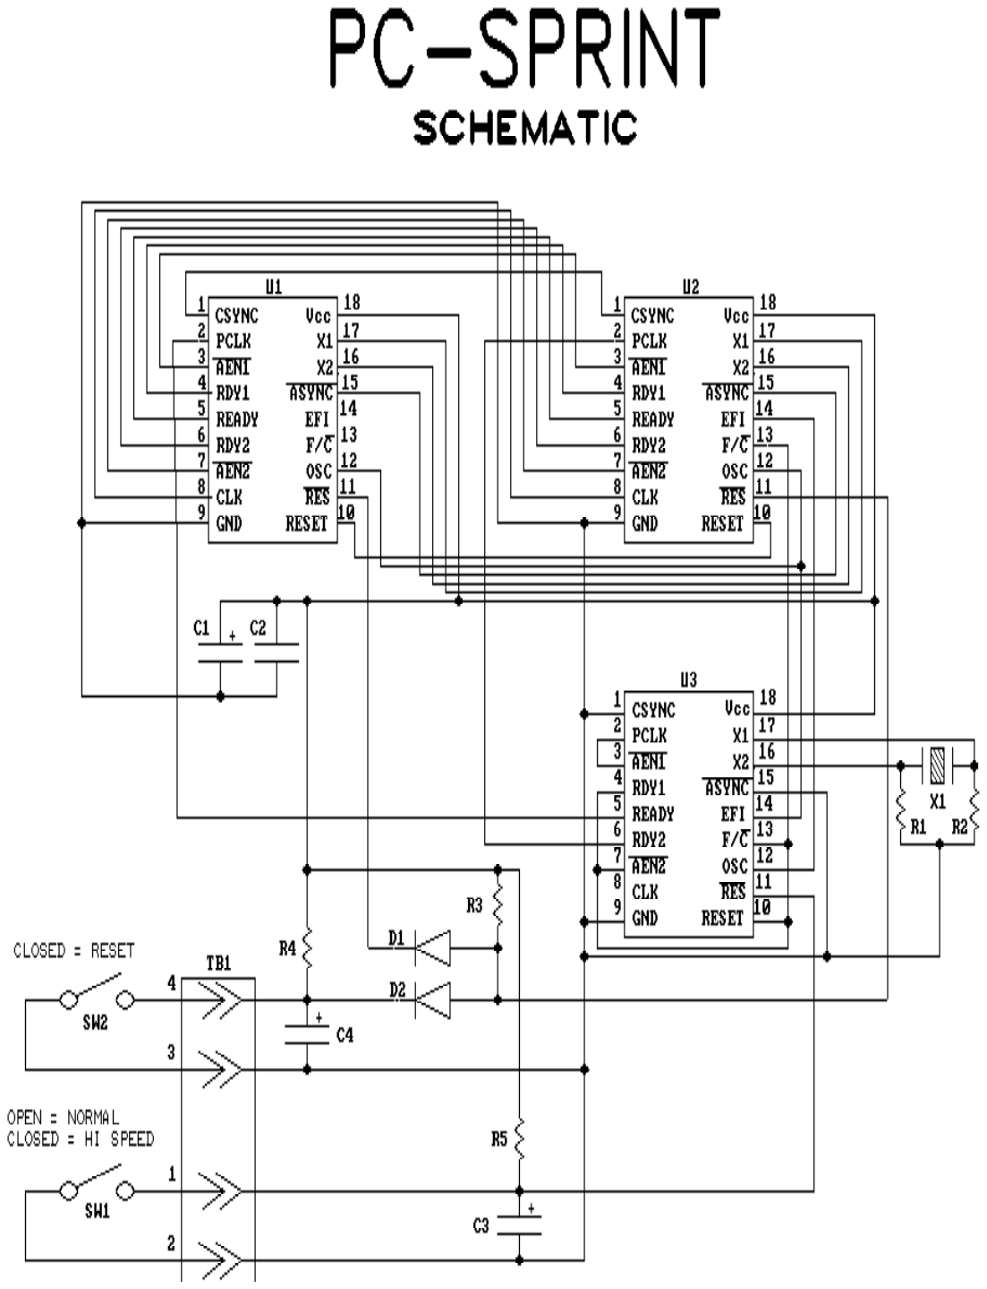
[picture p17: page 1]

≡ α

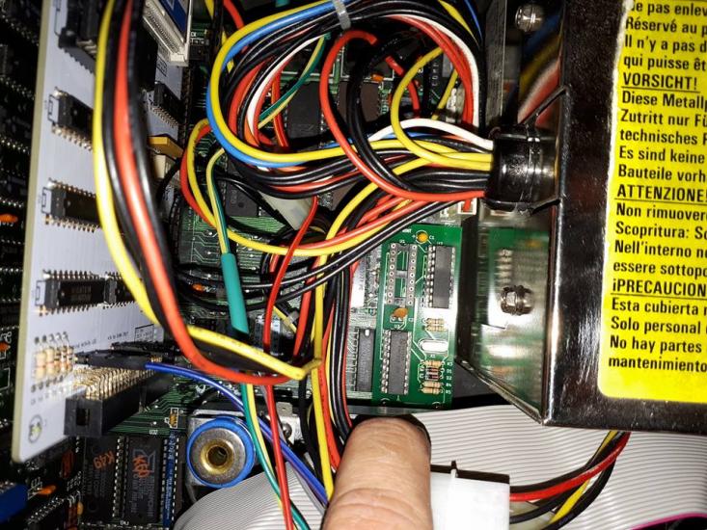
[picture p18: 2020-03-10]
Retro Canada/Images/pcsprint2.jpg

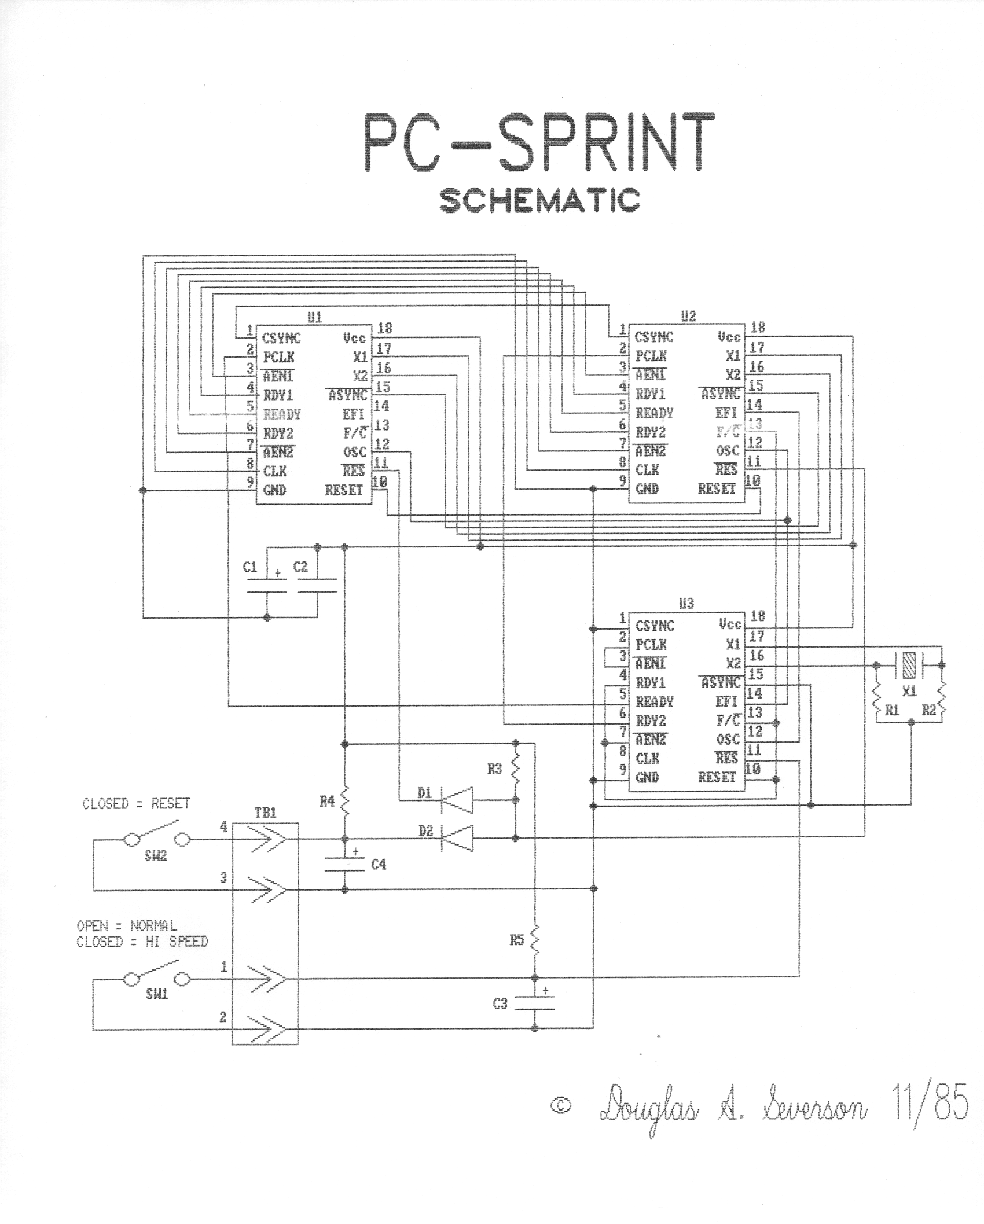
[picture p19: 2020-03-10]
SCHEMATC.TIF

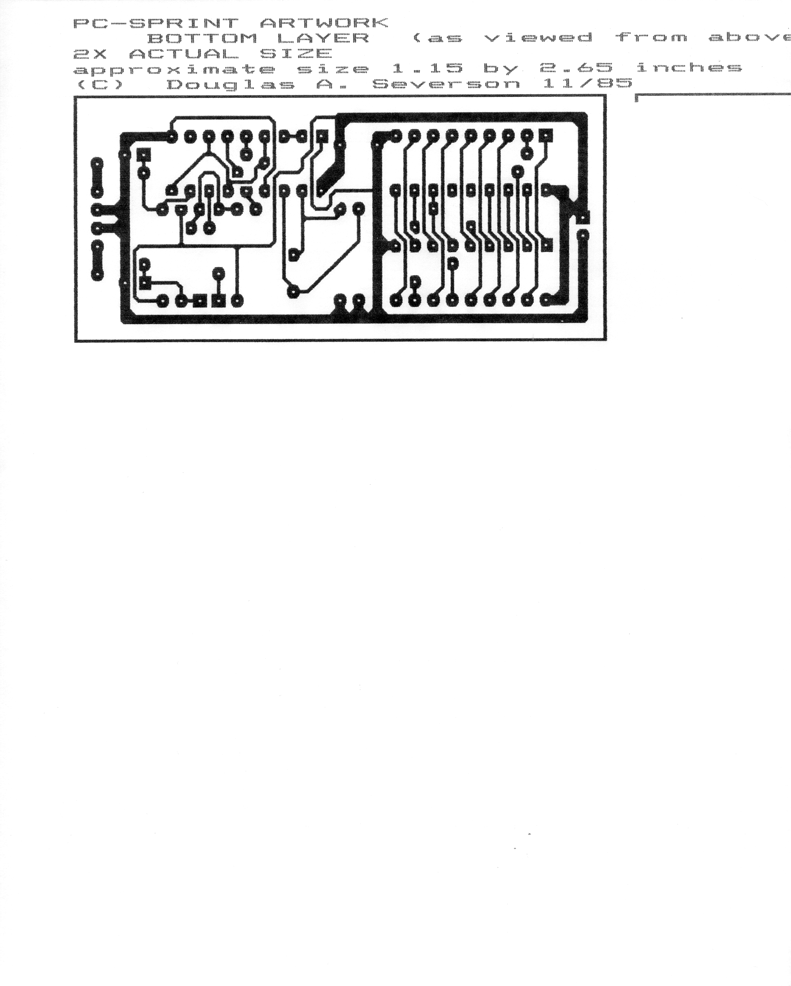
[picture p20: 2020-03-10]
ARTWRK2X.BOT.TIF

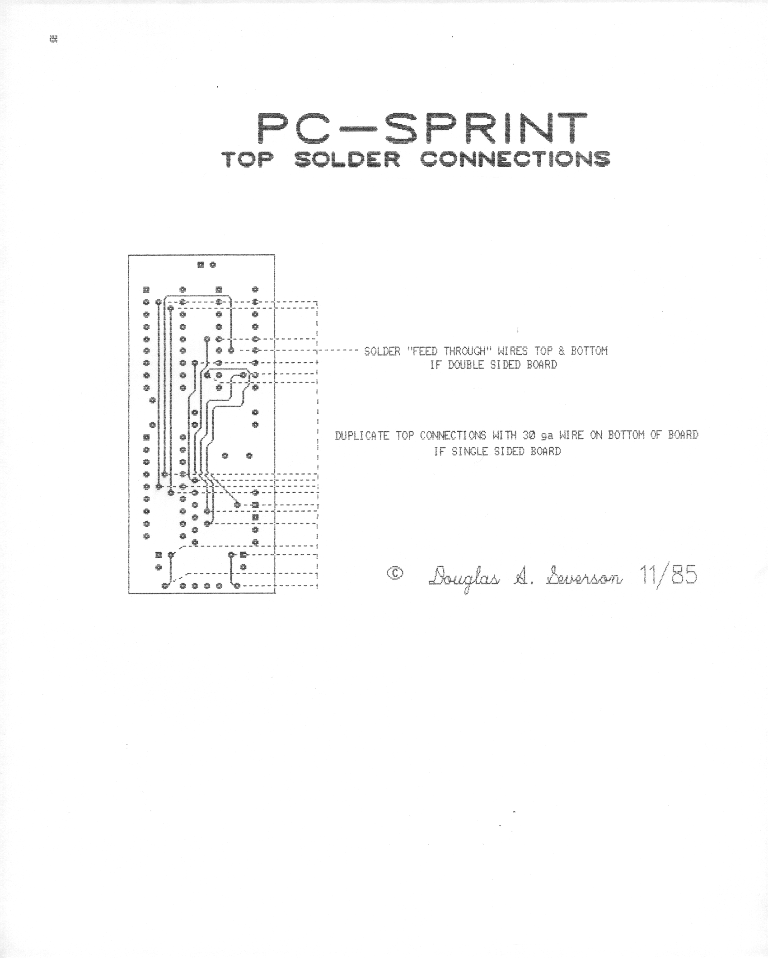
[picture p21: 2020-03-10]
FEEDTHRU.TIF

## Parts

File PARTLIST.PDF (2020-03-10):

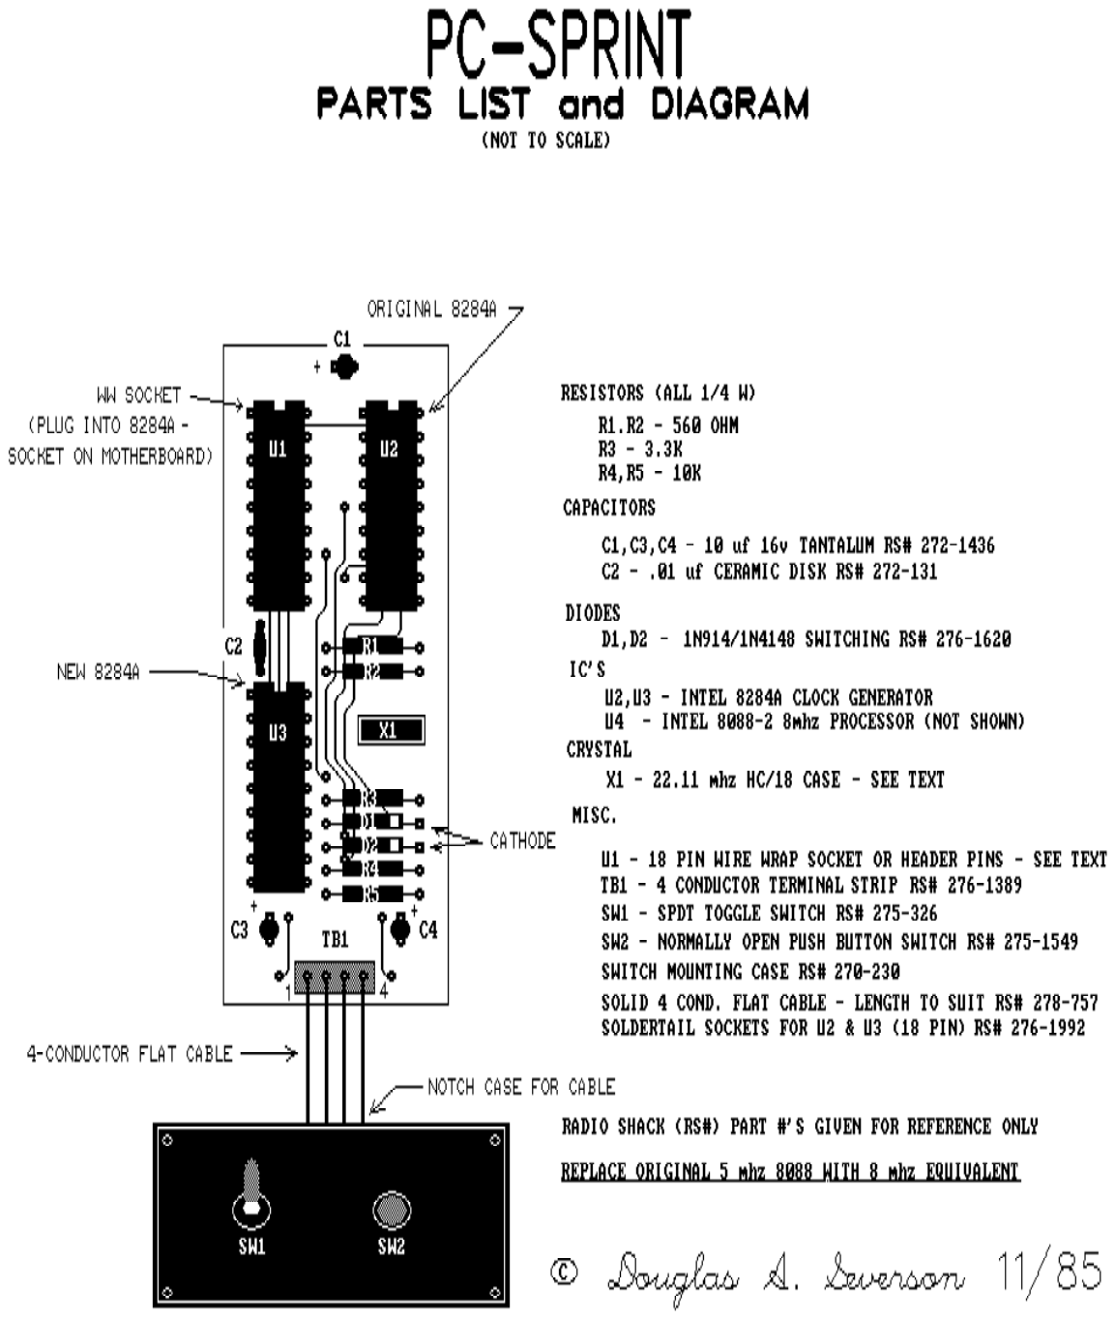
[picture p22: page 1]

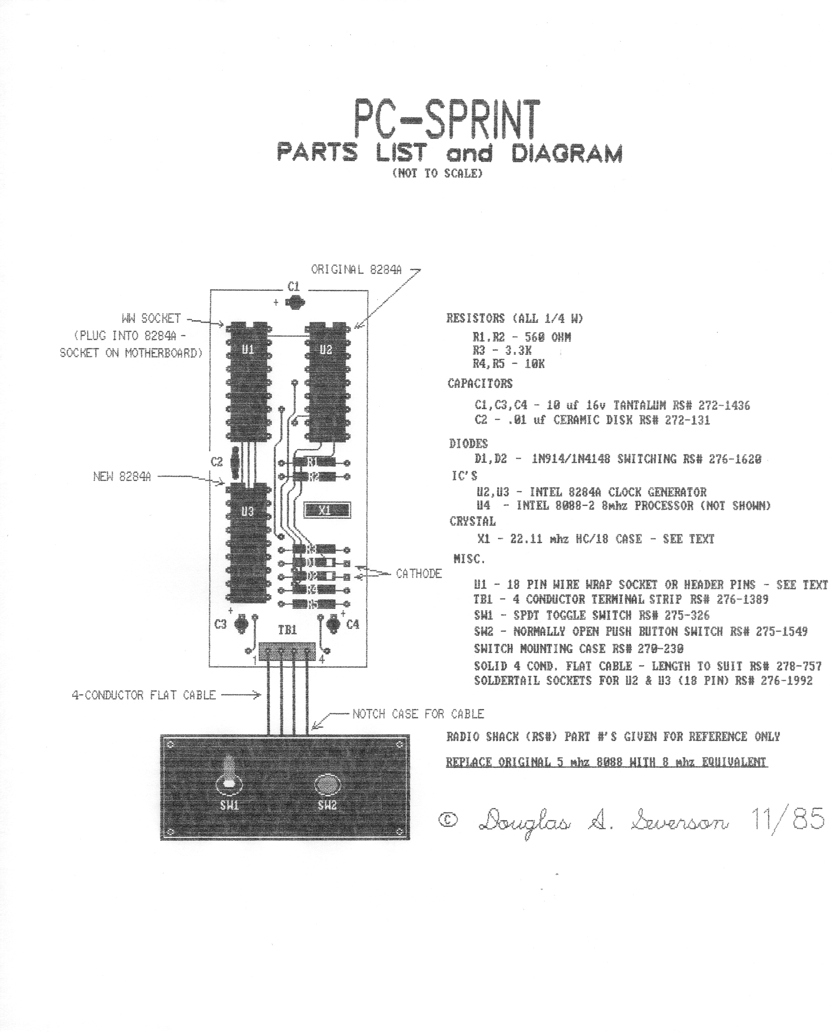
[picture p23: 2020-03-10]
PARTLIST.TIF

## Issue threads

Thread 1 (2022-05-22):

Info about Compaq Portable 1

cognitivegears, 2022-05-22:
Thank you so much for creating this repo and archiving this information!

I wanted to confirm that the PC-Sprint does work on the Compaq Portable 1 as well. A couple of notes on it:
* The 8284A on the Compaq Portable 1 is unfortunately soldered onto the motherboard, so a socket needs to be installed prior to using a PC-Sprint
* Due to the placement of the 8284A near the edge of the motherboard, when installed the original 5 1/4 inch drive in the first slot will overlap and not give room for the installation. In my case since I only had one 5 1/4 inch drive I moved it to the other bay.
* You will most likely need to install the PC-Sprint after installing the motherboard in the case due to the limited space. It is possible to reach the 8284A with the motherboard installed as long as the ISA cards are removed.
* I only tried a 21.47 mhz crystal so far but everything has been stable. Other cards include the original floppy controller card, original CGA card, an ISA CF card adapter and a SixPackPlus RAM Clock I/O board. The SixPackPlus does have some 200ns ram in one of the banks, but still seems to operate okay. The rest of the ram in the system is 150ns.
* I used a V20 D70108C-8 for the processor.
* My Compaq has a 8087-1 and worked without issues.

Other notes:
* You may want to mention that for the headers you need to get round pin headers that fit into DIP sockets - the regular rectangular pins for breadboards etc won't fit.
* I'm not sure if you are good with commercial links, but I used this link [PCBWay](https://www.pcbway.com/project/shareproject/PC_Sprint_Accelerator.html). I'm not associated in any way, just worked well for me.

reeshub, 2022-05-22:
Thanks so much for the detailed information! So great to hear that this also works well with the Compaq Portable 1. I'll try to get the page updated as soon as I can.

No problem at all with recommendations for professional services, I also used PCBWay to manufacture my boards and they were great. I've also had good experiences with JLCPCB - due to the simplicity of the board I should think that any commercial PCB fab can handle it just fine.

Interesting to hear about the 200ns RAM in the SixPakPlus, that's also very useful to know.

cognitivegears, 2022-06-13:
A couple of pictures from the Compaq as well:

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

AtomicLunchbox, 2023-04-11:
Just wanted to add a couple of notes. I built one of these too for my Compaq Portable I

1) I don't think @cognitivegears has an original disk drive in his machine. The Compaq Portable used full height drives and the PC sprint blocks both bays. I've been looking for a solution to relocate it but haven't found a readily available ribbon cable/socket. A slight modification to the board layout might make the first bay (nearest to the monitor) accessible.
2) My configuration is similar: V20 + 8087-1, oem cga/mda card, oem floppy controller, AST MegaPak II (RAM + Clock) and XT-CF card
3) I've only tried a 22.11MHz crystal and everything was stable at the faster speed with the exception of the disk drive which seemed flaky. I didn't narrow that down to the controller or the drive itself.

If I come up with a good way to install the PCB and use the disk drive, I'll follow up.

cognitivegears, 2023-10-11:
Thanks @AtomicLunchbox - I have one original drive, though without the original cage. For the other one I was missing the original drive, so I made a 3d printed enclosure that has a gotek, as well as now a reset button and turbo button (connected to the PC-Sprint.) You can see the purple housing in one of the pictures that I posted.

I'm not sure how it could block both bays, but the closest bay I could definitely see it blocking without a replacement like I'm using.

AtomicLunchbox, 2023-10-14:
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

@cognitivegears take look at the pictures above. Full height floppy (original) prevents the pc-sprint from being installed. There just isn't enough room. Your drive is a lot shorter than mine so I was assuming it's half height.

Synoptic2, 2024-01-09:
Hi gang! I am currently testing the pc-sprint on my Compaq board revision 1. I tried a 24mhz crystal and it fails with a RAM error 0002 201.

I know it is probably because it is too fast.
what DRAM chip do you all have to be able to run it using a 22mhz crystal? Are the stock ram chips fast enough?

AtomicLunchbox, 2024-01-13:
Mine is a Portable Plus, but it has the revision 1 board. The DRAM appears to be stock 200ns chips soldered on and 250 in the socketed banks. I also have an ISA RAM card with another 256K of 250ns parts.

MicrowaveableTupperware, 2024-03-25:
Has anyone tried the Skinny Sprint V2 by Epictronics? It’s smaller and may fit under the floppy drive

https://github.com/epictronics/Skinny-Sprint/tree/main

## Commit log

2020-03-10 Added Retro Canada release
    [PC-SPRINT-B.Cu.gbr, PC-SPRINT-B.Mask.gbr, PC-SPRINT-B.SilkS.gbr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]
2020-03-10 Added Retro Canada unzipped files
    [PC-SPRINT-B.Cu.gbr, PC-SPRINT-B.Mask.gbr, PC-SPRINT-B.SilkS.gbr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]
2020-03-10 Added PC-SPRINT v2 information and files
    [PC-SPRINT-B.Cu.gbr, PC-SPRINT-B.Mask.gbr, PC-SPRINT-B.SilkS.gbr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]
2020-03-16 Added some info based on my testing with the Retro Canada PCB, also added pics of my PCB
2020-03-16 Added DMA Information For v2
2020-03-16 Add New DMA Section To Index
2020-03-20 Separate v2 Stuff Into Its Own Area With Its Own README
    [PC-SPRINT-B_Cu.gbr, PC-SPRINT-B_Mask.gbr, PC-SPRINT-B_SilkS.gbr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]
2020-03-20 PC-SPRINT v2 Current Status Update
2020-03-20 V2: Added BOM & Timing Info
2020-03-31 Remove PC-SPRINT v2 Info Pending Further Work
    [PC-SPRINT-B_Cu.gbr, PC-SPRINT-B_Mask.gbr, PC-SPRINT-B_SilkS.gbr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]
